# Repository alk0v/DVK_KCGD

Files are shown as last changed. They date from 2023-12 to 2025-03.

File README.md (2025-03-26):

This project is a replica of a color graphic display controller (KCGD) for a DVK computer, reproduced in full accordance with the schematic diagram. Unfortunately, I lost the latest version of the project in KiCAD along with the SSD disk, so the repository contains only what I managed to restore from the backup (about 50% of the finished project). However, the Gerber files were saved.
The boards have been ordered, and one board has been assembled, but unfortunately, there is no way to check its operation. The DVK computer is currently unavailable due to the war in Ukraine.

Цей проект - репліка контролера кольорового графічного дисплею (КЦГД) для комп'ютера ДВК, відтворена у повній відповідності до принципової схеми. На жаль, останню версію проекту в KiCAD я втратив разом з SSD диском, то ж в репозиторії лише те, що вдалося відновити з бекапа (десь 50% готового проекту). Але  зберіглися gerber-файли.
Плати були замовлені, одна плата зібрана, але перевірити її роботу, на жаль, нема можливості. Комп'ютер ДВК зараз недоступний через війну.

gerber_image
kcgd_pcb2
kcgd_pcb1

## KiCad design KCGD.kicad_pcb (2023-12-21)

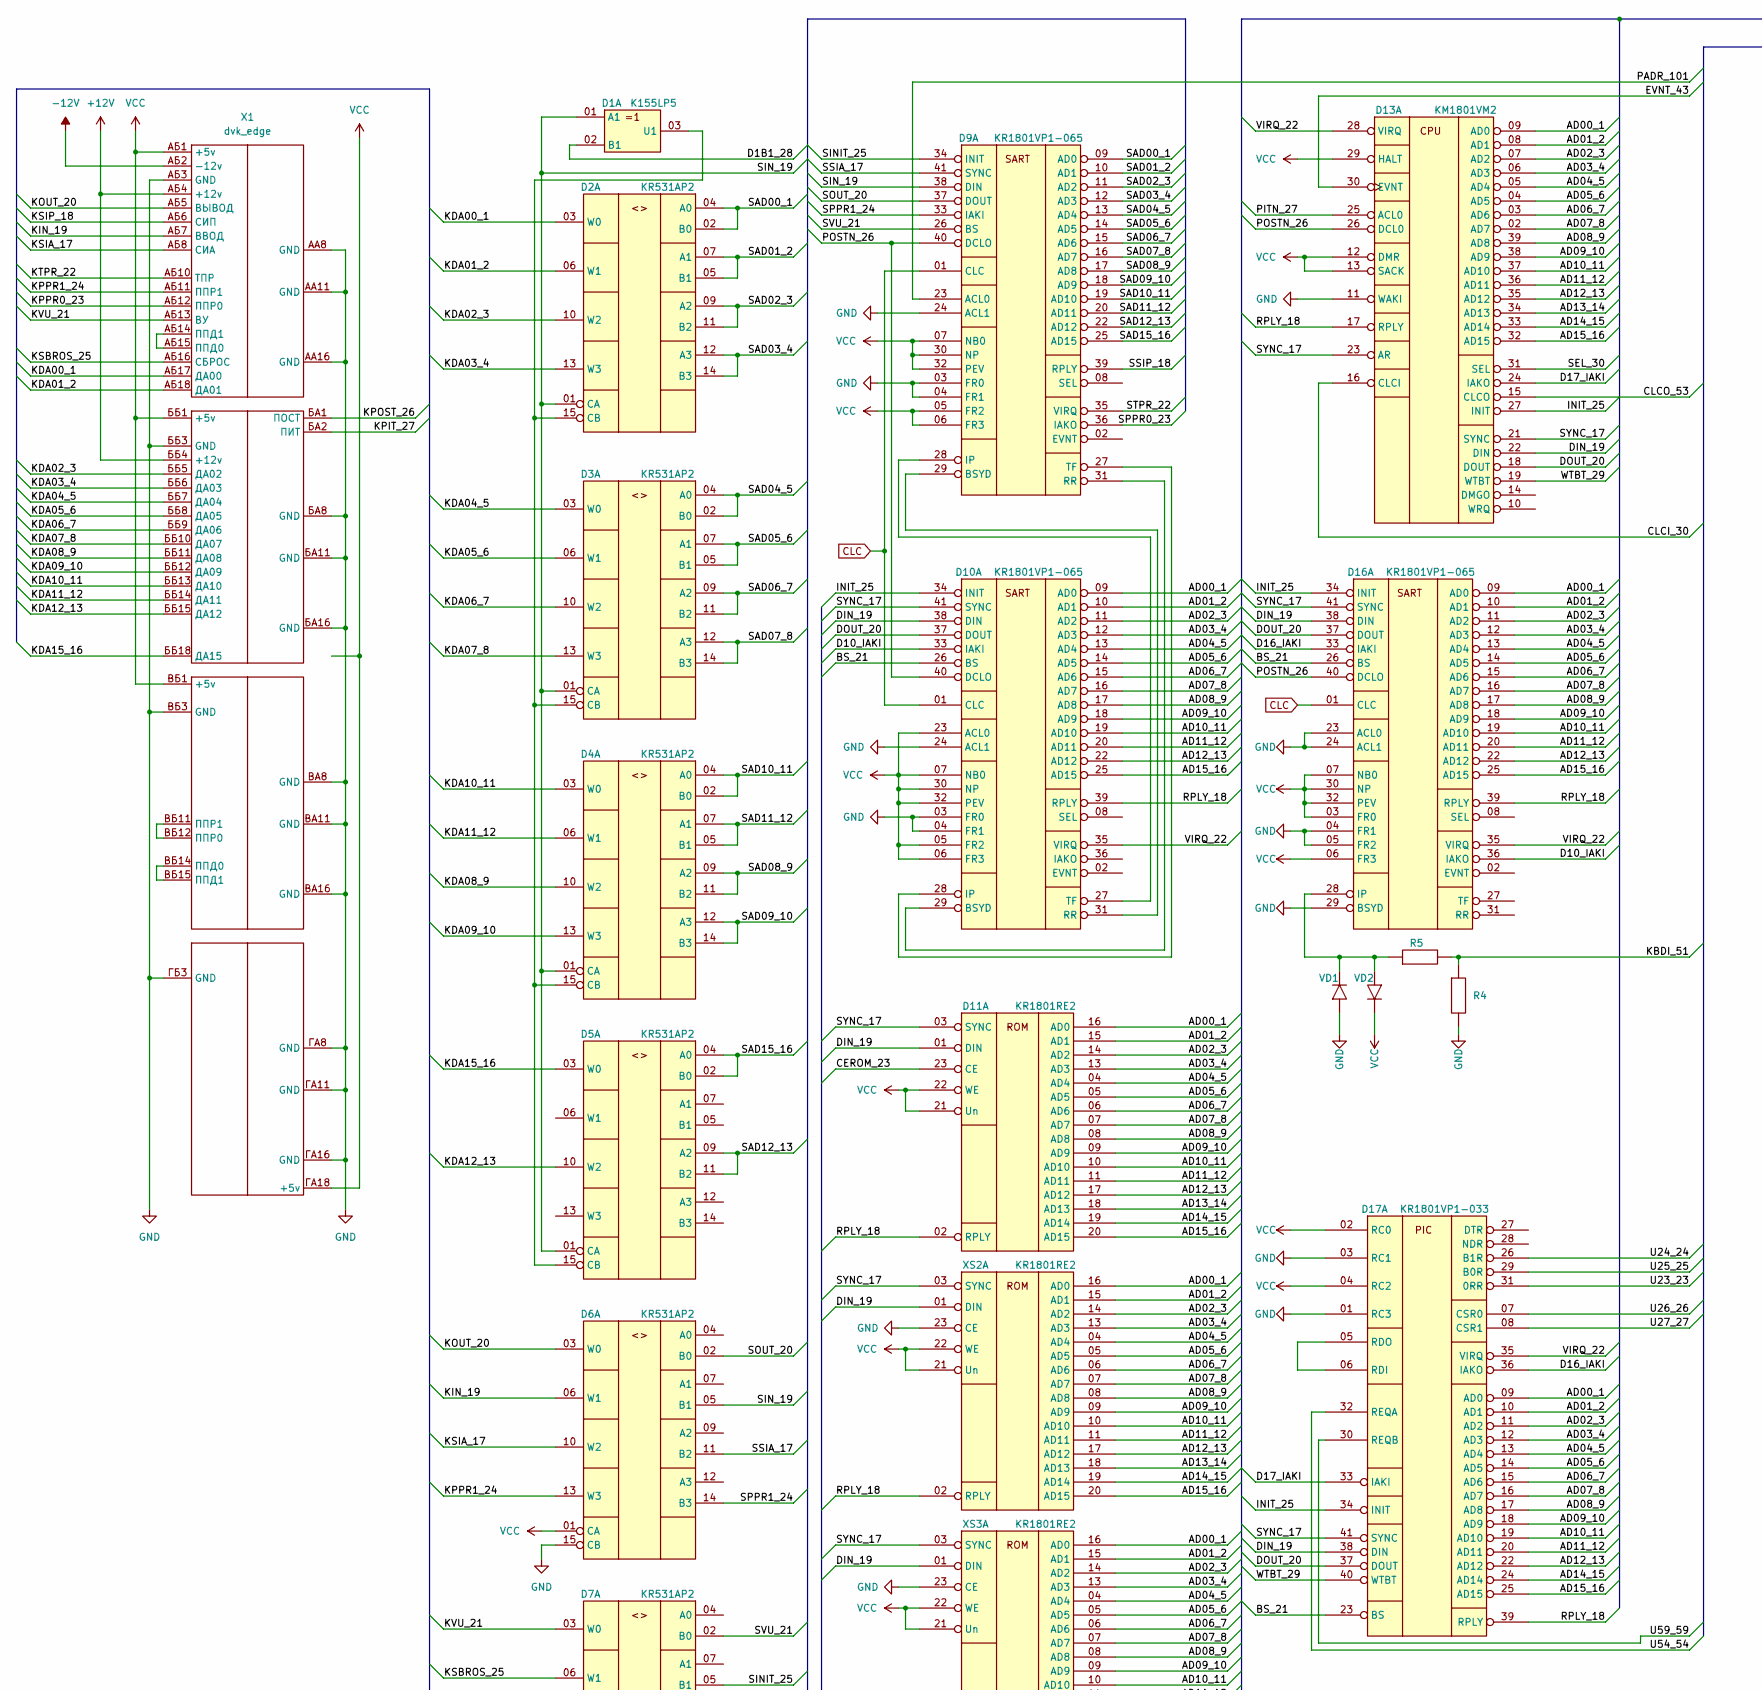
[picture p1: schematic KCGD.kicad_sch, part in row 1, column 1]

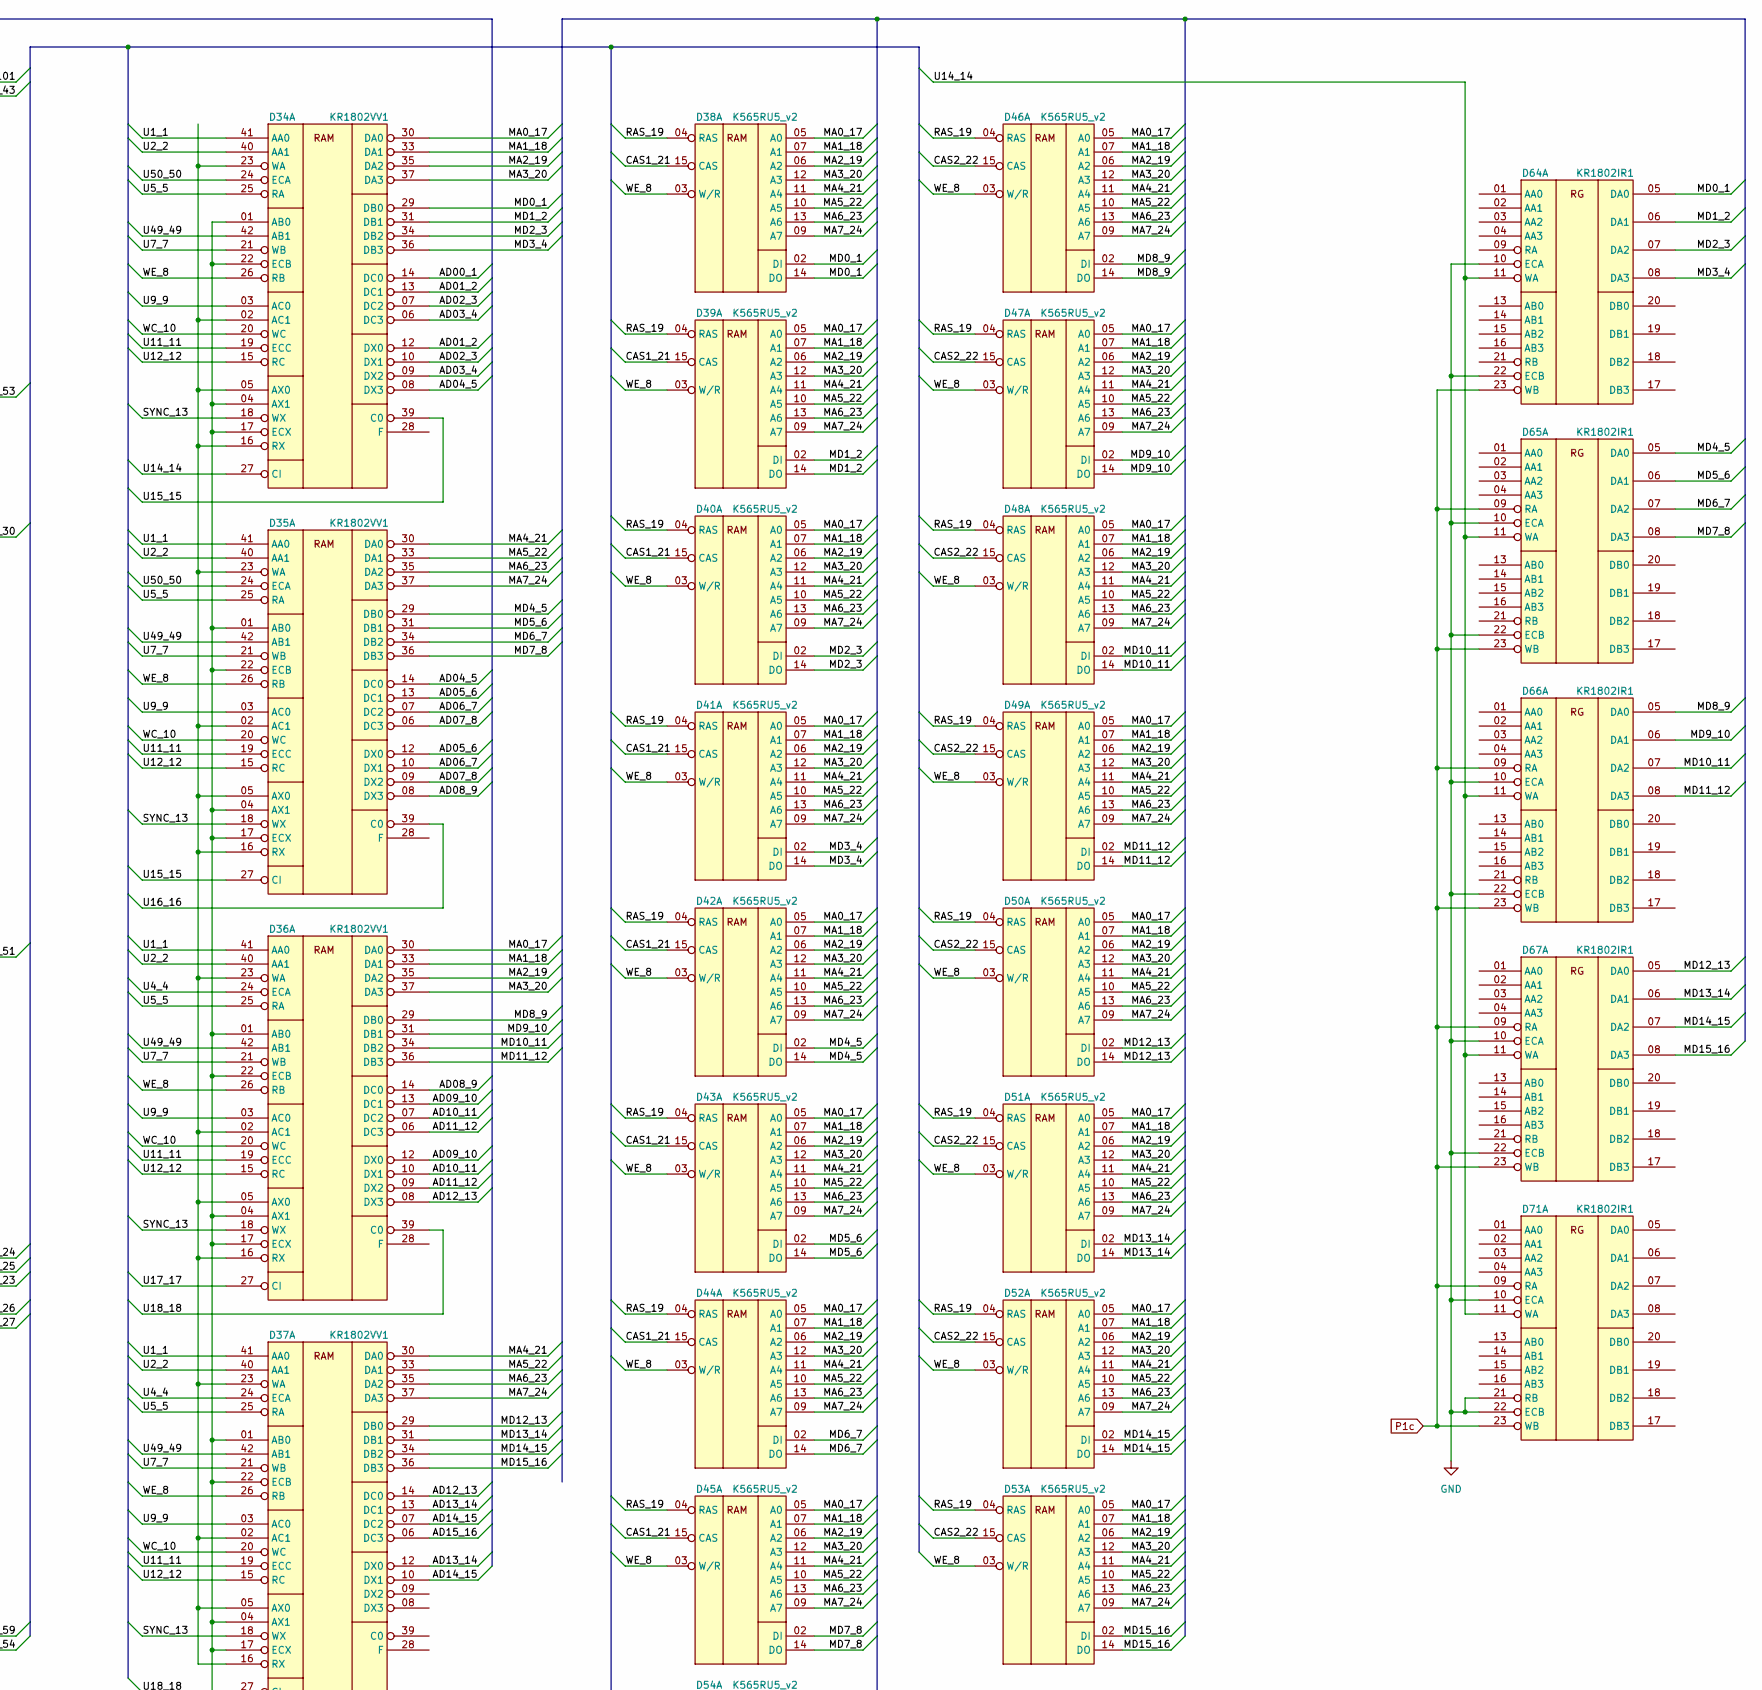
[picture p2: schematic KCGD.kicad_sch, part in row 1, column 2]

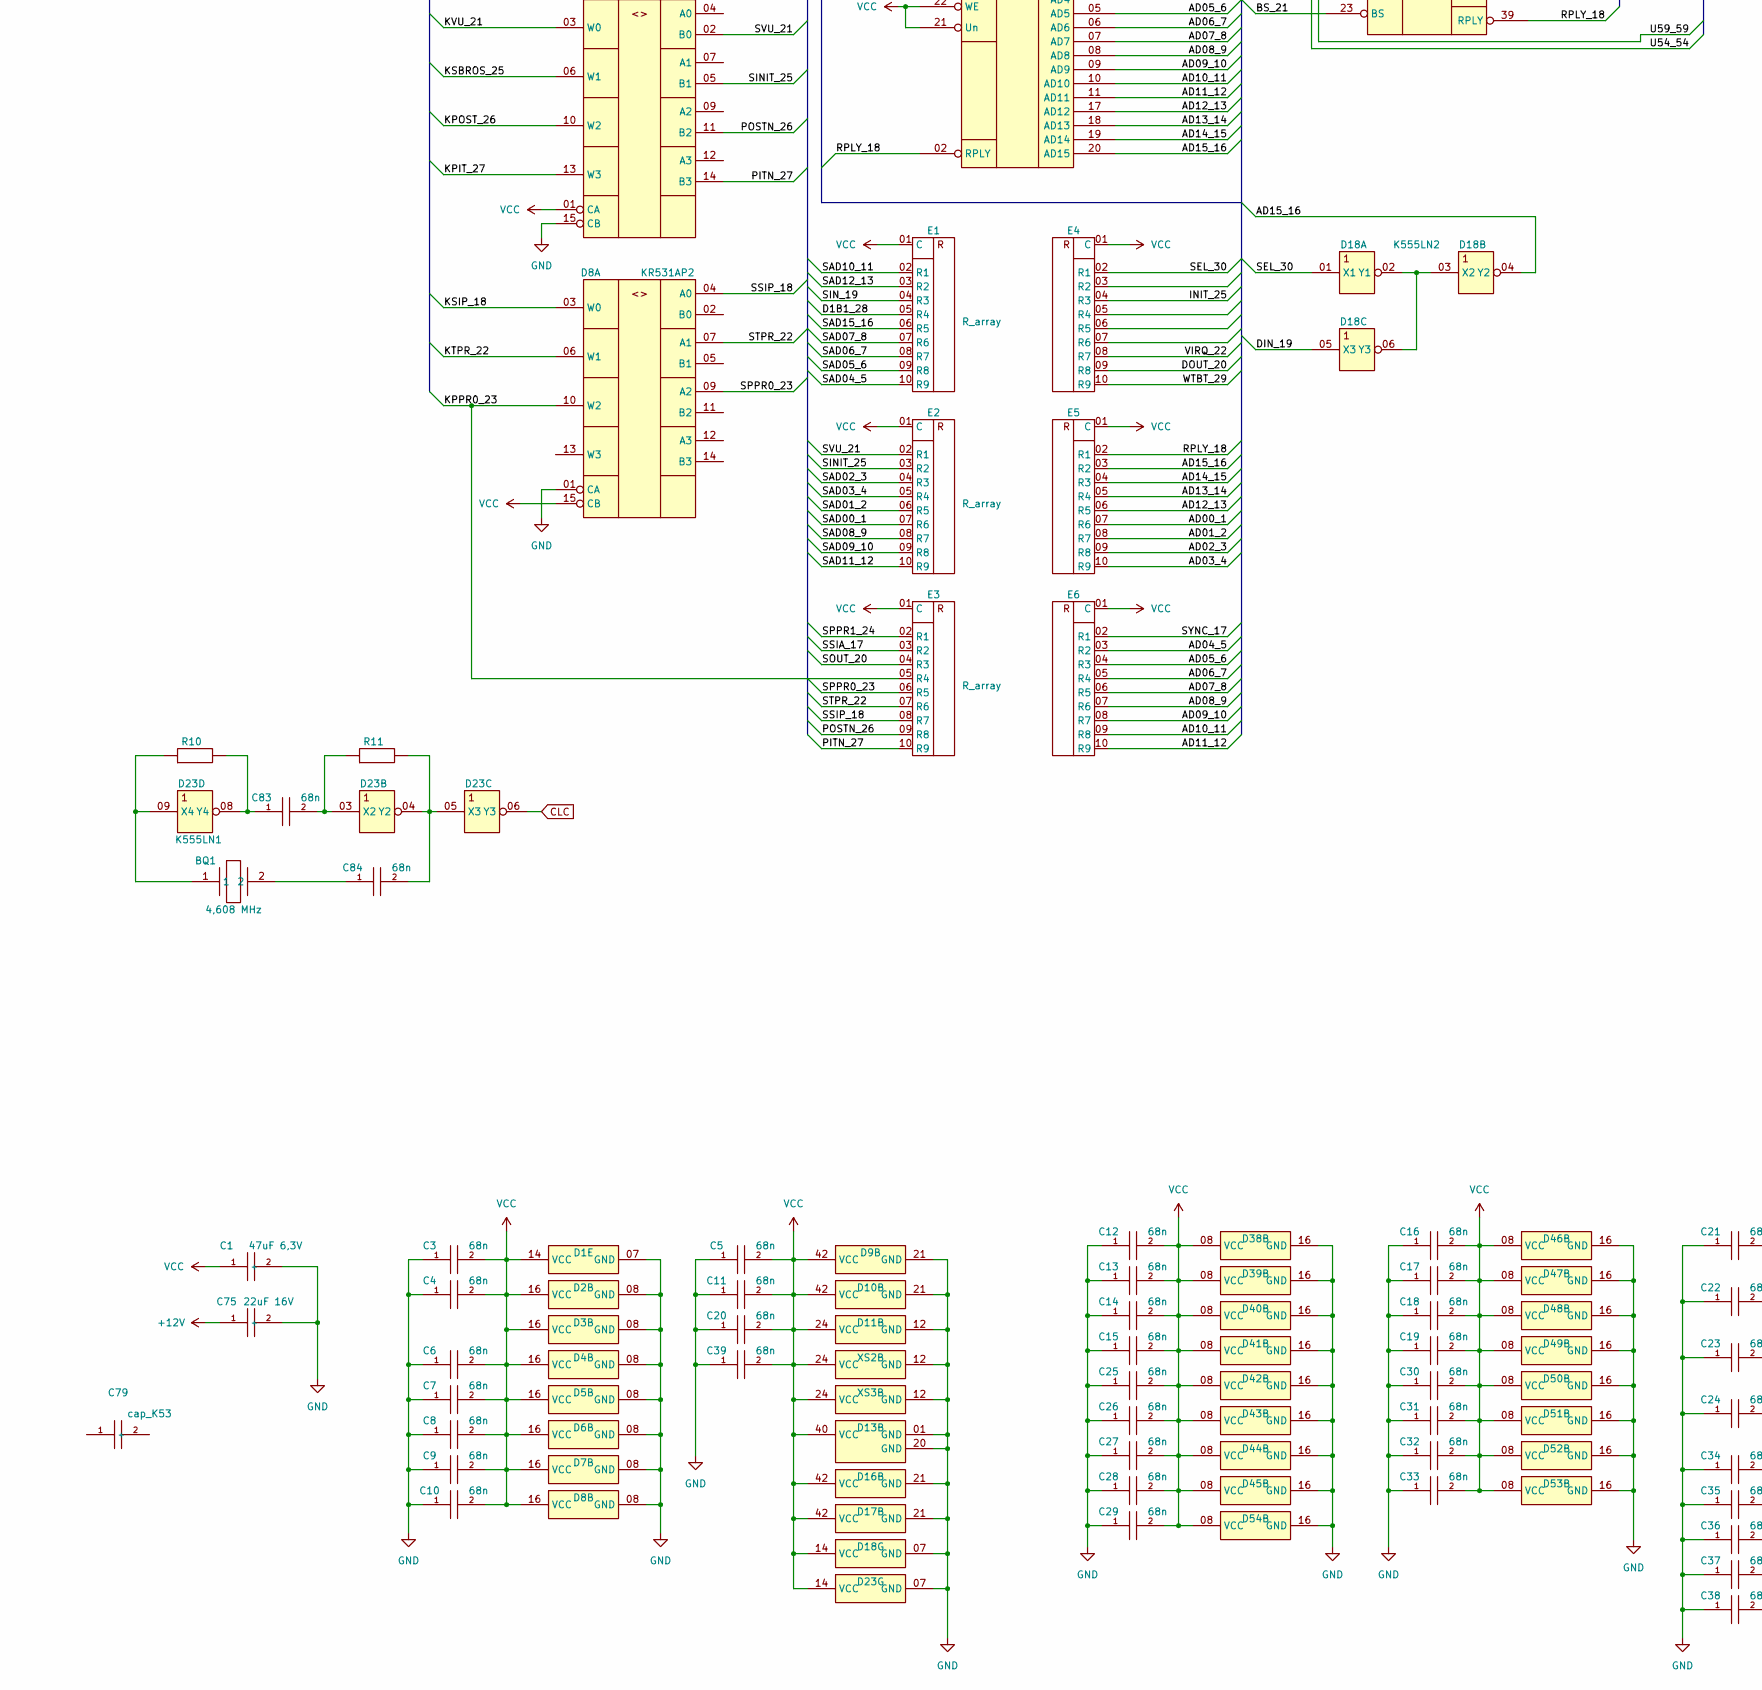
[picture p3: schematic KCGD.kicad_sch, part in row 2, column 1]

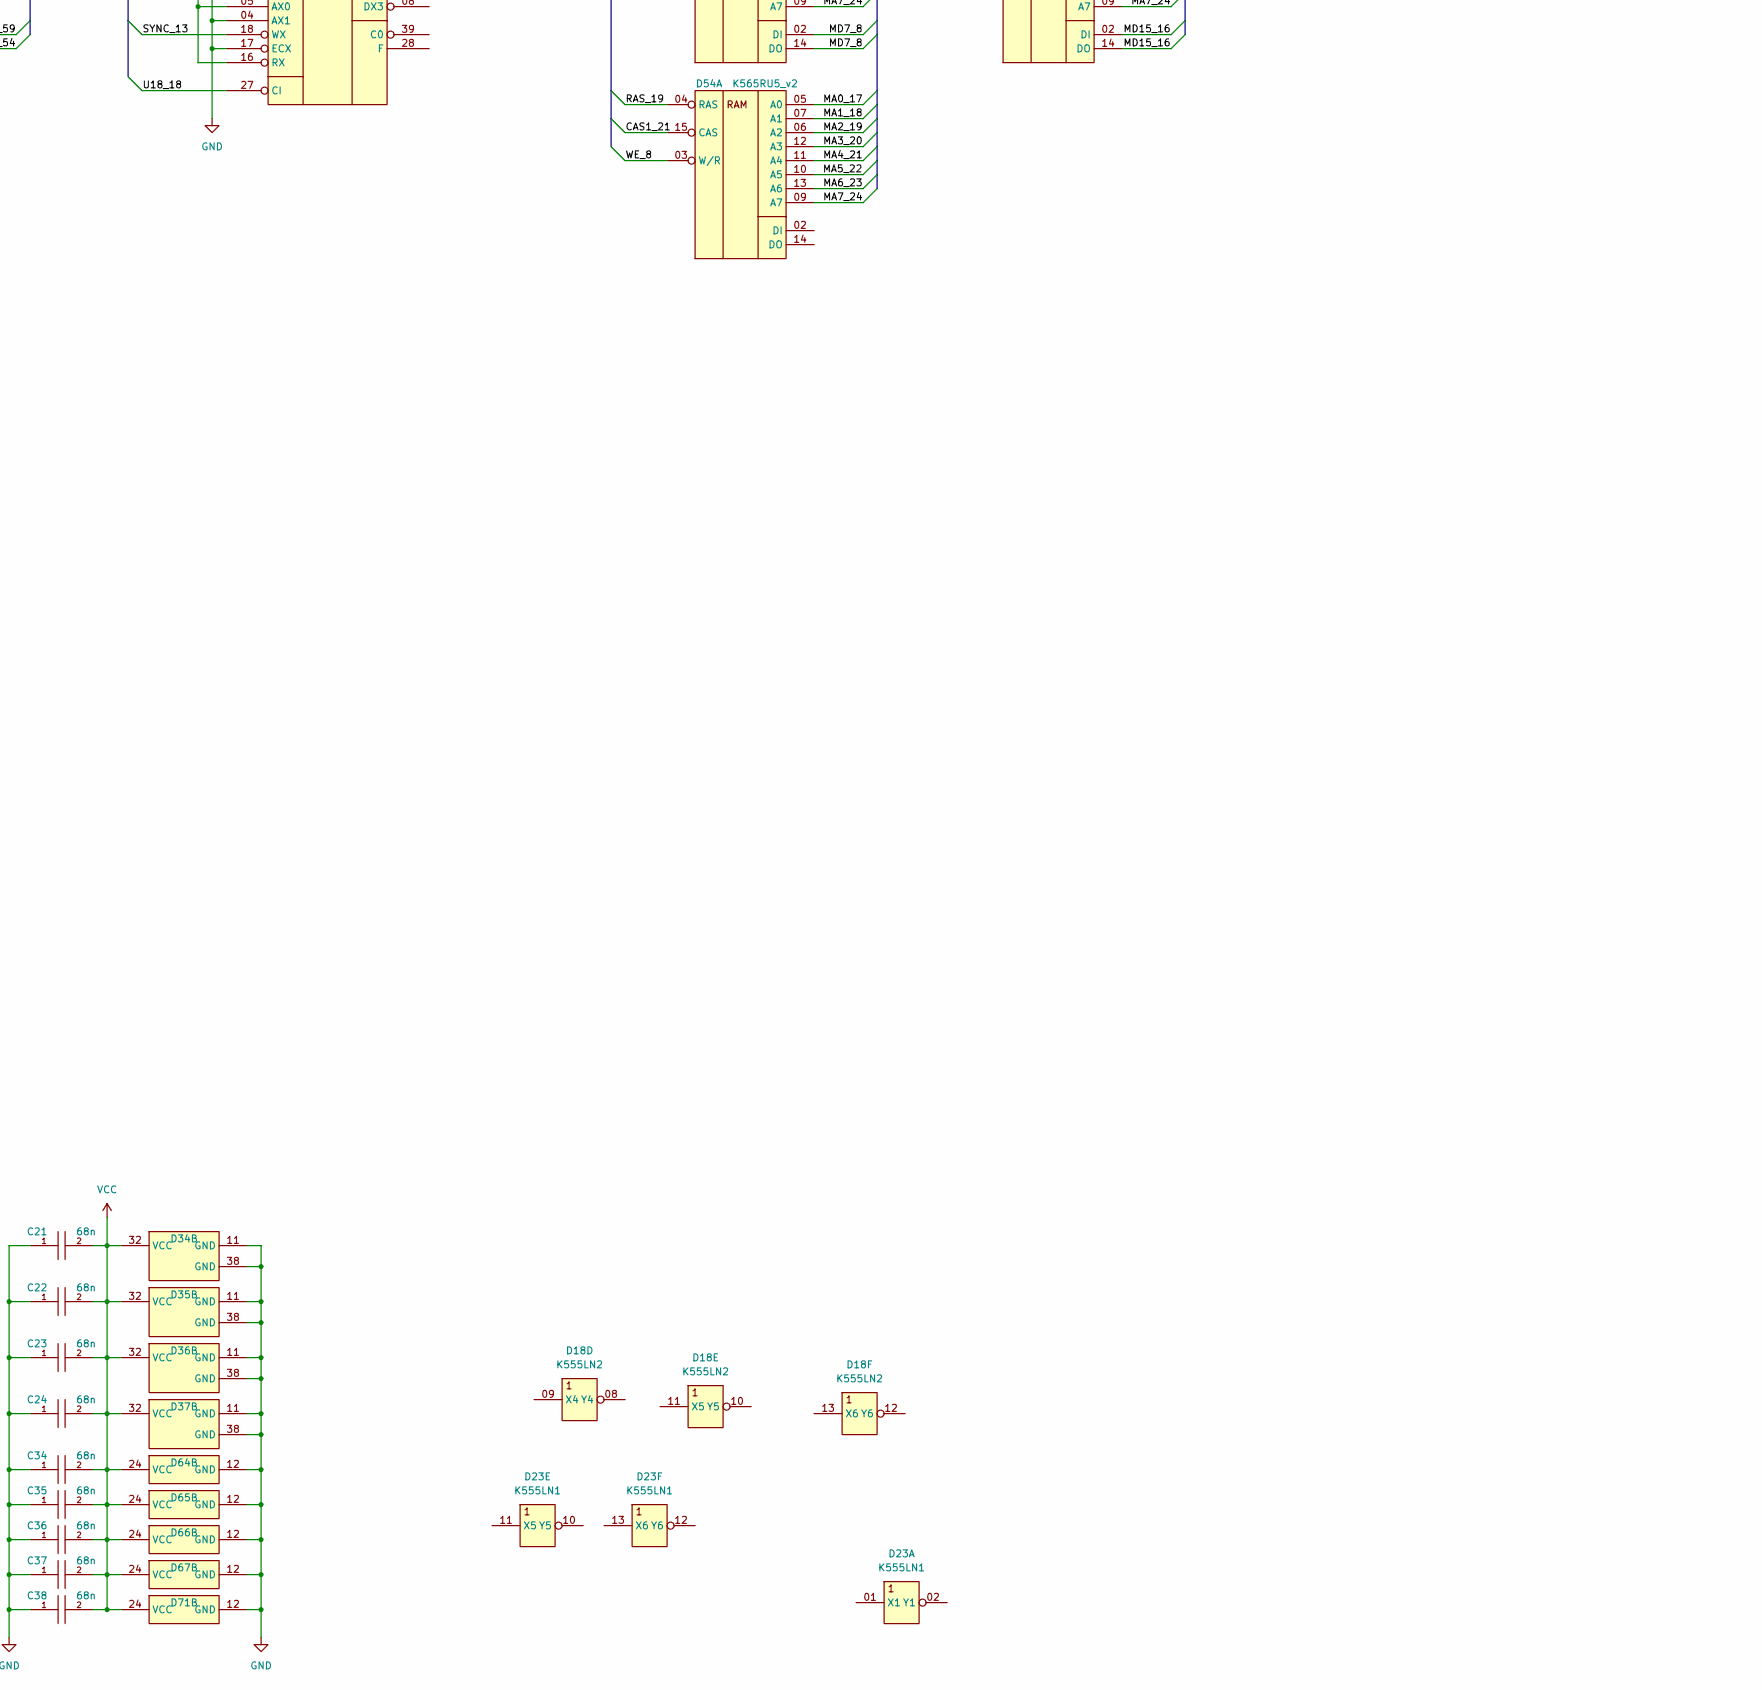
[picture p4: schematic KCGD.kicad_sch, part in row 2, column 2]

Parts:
BQ1: 4,608 MHz; Quartz
C1: 47uF 6,3V; cap_K53
C3, C4, C5, C6, C7, C8, C9, C10, C11, C12, C13, C14, C15, C16, C17, C18, C19, C20, C21, C22, C23, C24, C25, C26, C27, C28, C29, C30, C31, C32, C33, C34, C35, C36, C37, C38, C39, C83, C84: 68n; cap_5mm
C75: 22uF 16V; cap_K53
C79: cap_K53
D1: K155LP5; 201.14-8
D2, D3, D4, D5, D6, D7, D8: KR531AP2; 201.16.5
D9, D10, D16: КR1801VP1-065; 429.42-5
D11: KR1801RE2; 239.24-2
D13: KM1801VM2; 2123.40-6
D17: KR1801VP1-033; 429.42-5
D18: K555LN2; 201.14-8
D23: K555LN1; 201.14-8
D34, D35, D36, D37: KR1802VV1; 429.42-5
D38, D39, D40, D41, D42, D43, D44, D45, D46, D47, D48, D49, D50, D51, D52, D53, D54: K565RU5_v2; 201.16.5
D64, D65, D66, D67, D71: KR1802IR1; 239.24-2
E1, E2, E3, E4, E5, E6: R_array; row-10
R4: 3,3k; 2pin_125
R5: 62k; 2pin_125
R10, R11: 1k; 2pin_125
VD1, VD2: VD_125; 2pin_125
X1: dvk_edge; dvk_edge_kcgd
XS2, XS3: KR1801RE2; 239.24-2

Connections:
+12V: C75.1 (+), X1.АБ4 (+12v), X1.ББ4 (+12v)
-12V: X1.АБ2 (-12v)
/AD00_1: D10.09 (AD0), D11.16 (AD0), D13.09 (AD0), D16.09 (AD0), D17.09 (AD0), D34.14 (DC0), E5.07 (R6), XS2.16 (AD0), XS3.16 (AD0)
/AD01_2: D10.10 (AD1), D11.15 (AD1), D13.08 (AD1), D16.10 (AD1), D17.10 (AD1), D34.12 (DX0), D34.13 (DC1), E5.08 (R7), XS2.15 (AD1), XS3.15 (AD1)
/AD02_3: D10.11 (AD2), D11.14 (AD2), D13.07 (AD2), D16.11 (AD2), D17.11 (AD2), D34.07 (DC2), D34.10 (DX1), E5.09 (R8), XS2.14 (AD2), XS3.14 (AD2)
/AD03_4: D10.12 (AD3), D11.13 (AD3), D13.06 (AD3), D16.12 (AD3), D17.12 (AD3), D34.06 (DC3), D34.09 (DX2), E5.10 (R9), XS2.13 (AD3), XS3.13 (AD3)
/AD04_5: D10.13 (AD4), D11.04 (AD4), D13.05 (AD4), D16.13 (AD4), D17.13 (AD4), D34.08 (DX3), D35.14 (DC0), E6.03 (R2), XS2.04 (AD4), XS3.04 (AD4)
/AD05_6: D10.14 (AD5), D11.05 (AD5), D13.04 (AD5), D16.14 (AD5), D17.14 (AD5), D35.12 (DX0), D35.13 (DC1), E6.04 (R3), XS2.05 (AD5), XS3.05 (AD5)
/AD06_7: D10.15 (AD6), D11.06 (AD6), D13.03 (AD6), D16.15 (AD6), D17.15 (AD6), D35.07 (DC2), D35.10 (DX1), E6.05 (R4), XS2.06 (AD6), XS3.06 (AD6)
/AD07_8: D10.16 (AD7), D11.07 (AD7), D13.02 (AD7), D16.16 (AD7), D17.16 (AD7), D35.06 (DC3), D35.09 (DX2), E6.06 (R5), XS2.07 (AD7), XS3.07 (AD7)
/AD08_9: D10.17 (AD8), D11.08 (AD8), D13.39 (AD8), D16.17 (AD8), D17.17 (AD8), D35.08 (DX3), D36.14 (DC0), E6.07 (R6), XS2.08 (AD8), XS3.08 (AD8)
/AD09_10: D10.18 (AD9), D11.09 (AD9), D13.38 (AD9), D16.18 (AD9), D17.18 (AD9), D36.12 (DX0), D36.13 (DC1), E6.08 (R7), XS2.09 (AD9), XS3.09 (AD9)
/AD10_11: D10.19 (AD10), D11.10 (AD10), D13.37 (AD10), D16.19 (AD10), D17.19 (AD10), D36.07 (DC2), D36.10 (DX1), E6.09 (R8), XS2.10 (AD10), XS3.10 (AD10)
/AD11_12: D10.20 (AD11), D11.11 (AD11), D13.36 (AD11), D16.20 (AD11), D17.20 (AD11), D36.06 (DC3), D36.09 (DX2), E6.10 (R9), XS2.11 (AD11), XS3.11 (AD11)
/AD12_13: D10.22 (AD12), D11.17 (AD12), D13.35 (AD12), D16.22 (AD12), D17.22 (AD12), D36.08 (DX3), D37.14 (DC0), E5.06 (R5), XS2.17 (AD12), XS3.17 (AD12)
/AD13_14: D11.18 (AD13), D13.34 (AD13), D37.12 (DX0), D37.13 (DC1), E5.05 (R4), XS2.18 (AD13), XS3.18 (AD13)
/AD14_15: D11.19 (AD14), D13.33 (AD14), D17.24 (AD14), D37.07 (DC2), D37.10 (DX1), E5.04 (R3), XS2.19 (AD14), XS3.19 (AD14)
/AD15_16: D11.20 (AD15), D13.32 (AD15), D16.25 (AD15), D17.25 (AD15), D18.04 (Y2), D37.06 (DC3), E5.03 (R2), XS2.20 (AD15), XS3.20 (AD15)
/BS_21: D10.26 (BS), D16.26 (BS), D17.23 (BS)
/CAS1_21: D38.15 (CAS), D39.15 (CAS), D40.15 (CAS), D41.15 (CAS), D42.15 (CAS), D43.15 (CAS), D44.15 (CAS), D45.15 (CAS), D54.15 (CAS)
/CAS2_22: D46.15 (CAS), D47.15 (CAS), D48.15 (CAS), D49.15 (CAS), D50.15 (CAS), D51.15 (CAS), D52.15 (CAS), D53.15 (CAS)
/CEROM_23: D11.23 (CE)
/CLCI_30: D13.16 (CLCI)
/CLCO_53: D13.15 (CLCO)
/D1B1_28: D1.02 (B1), E1.05 (R4)
/D10_IAKI: D10.33 (IAKI), D16.36 (IAKO)
/D16_IAKI: D16.33 (IAKI), D17.36 (IAKO)
/D17_IAKI: D13.24 (IAKO), D17.33 (IAKI)
/DIN_19: D10.38 (DIN), D11.01 (DIN), D13.22 (DIN), D16.38 (DIN), D17.38 (DIN), D18.05 (X3), XS2.01 (DIN), XS3.01 (DIN)
/DOUT_20: D10.37 (DOUT), D13.18 (DOUT), D16.37 (DOUT), D17.37 (DOUT), E4.09 (R8)
/EVNT_43: D13.30 (EVNT)
/INIT_25: D10.34 (INIT), D13.27 (INIT), D16.34 (INIT), D17.34 (INIT), E4.04 (R3)
/KBDI_51: R4.1, R5.2
/KDA00_1: D2.03 (W0), X1.АБ17 (ДА00)
/KDA01_2: D2.06 (W1), X1.АБ18 (ДА01)
/KDA02_3: D2.10 (W2), X1.ББ5 (ДА02)
/KDA03_4: D2.13 (W3), X1.ББ6 (ДА03)
/KDA04_5: D3.03 (W0), X1.ББ7 (ДА04)
/KDA05_6: D3.06 (W1), X1.ББ8 (ДА05)
/KDA06_7: D3.10 (W2), X1.ББ9 (ДА06)
/KDA07_8: D3.13 (W3), X1.ББ10 (ДА07)
/KDA08_9: D4.10 (W2), X1.ББ11 (ДА08)
/KDA09_10: D4.13 (W3), X1.ББ12 (ДА09)
/KDA10_11: D4.03 (W0), X1.ББ13 (ДА10)
/KDA11_12: D4.06 (W1), X1.ББ14 (ДА11)
/KDA12_13: D5.10 (W2), X1.ББ15 (ДА12)
/KDA15_16: D5.03 (W0), X1.ББ18 (ДА15)
/KIN_19: D6.06 (W1), X1.АБ7 (ВВОД)
/KOUT_20: D6.03 (W0), X1.АБ5 (ВЫВОД)
/KPIT_27: D7.13 (W3), X1.БА2 (ПИТ)
/KPOST_26: D7.10 (W2), X1.БА1 (ПОСТ)
/KPPR0_23: D8.10 (W2), E3.05 (R4), X1.АБ12 (ППР0)
/KPPR1_24: D6.13 (W3), X1.АБ11 (ППР1)
/KSBROS_25: D7.06 (W1), X1.АБ16 (СБРОС)
/KSIA_17: D6.10 (W2), X1.АБ8 (СИА)
/KSIP_18: D8.03 (W0), X1.АБ6 (СИП)
/KTPR_22: D8.06 (W1), X1.АБ10 (ТПР)
/KVU_21: D7.03 (W0), X1.АБ13 (ВУ)
/MA0_17: D34.30 (DA0), D36.30 (DA0), D38.05 (A0), D39.05 (A0), D40.05 (A0), D41.05 (A0), D42.05 (A0), D43.05 (A0), D44.05 (A0), D45.05 (A0), D46.05 (A0), D47.05 (A0), D48.05 (A0), D49.05 (A0), D50.05 (A0), D51.05 (A0), D52.05 (A0), D53.05 (A0), D54.05 (A0)
/MA1_18: D34.33 (DA1), D36.33 (DA1), D38.07 (A1), D39.07 (A1), D40.07 (A1), D41.07 (A1), D42.07 (A1), D43.07 (A1), D44.07 (A1), D45.07 (A1), D46.07 (A1), D47.07 (A1), D48.07 (A1), D49.07 (A1), D50.07 (A1), D51.07 (A1), D52.07 (A1), D53.07 (A1), D54.07 (A1)
/MA2_19: D34.35 (DA2), D36.35 (DA2), D38.06 (A2), D39.06 (A2), D40.06 (A2), D41.06 (A2), D42.06 (A2), D43.06 (A2), D44.06 (A2), D45.06 (A2), D46.06 (A2), D47.06 (A2), D48.06 (A2), D49.06 (A2), D50.06 (A2), D51.06 (A2), D52.06 (A2), D53.06 (A2), D54.06 (A2)
/MA3_20: D34.37 (DA3), D36.37 (DA3), D38.12 (A3), D39.12 (A3), D40.12 (A3), D41.12 (A3), D42.12 (A3), D43.12 (A3), D44.12 (A3), D45.12 (A3), D46.12 (A3), D47.12 (A3), D48.12 (A3), D49.12 (A3), D50.12 (A3), D51.12 (A3), D52.12 (A3), D53.12 (A3), D54.12 (A3)
/MA4_21: D35.30 (DA0), D37.30 (DA0), D38.11 (A4), D39.11 (A4), D40.11 (A4), D41.11 (A4), D42.11 (A4), D43.11 (A4), D44.11 (A4), D45.11 (A4), D46.11 (A4), D47.11 (A4), D48.11 (A4), D49.11 (A4), D50.11 (A4), D51.11 (A4), D52.11 (A4), D53.11 (A4), D54.11 (A4)
/MA5_22: D35.33 (DA1), D37.33 (DA1), D38.10 (A5), D39.10 (A5), D40.10 (A5), D41.10 (A5), D42.10 (A5), D43.10 (A5), D44.10 (A5), D45.10 (A5), D46.10 (A5), D47.10 (A5), D48.10 (A5), D49.10 (A5), D50.10 (A5), D51.10 (A5), D52.10 (A5), D53.10 (A5), D54.10 (A5)
/MA6_23: D35.35 (DA2), D37.35 (DA2), D38.13 (A6), D39.13 (A6), D40.13 (A6), D41.13 (A6), D42.13 (A6), D43.13 (A6), D44.13 (A6), D45.13 (A6), D46.13 (A6), D47.13 (A6), D48.13 (A6), D49.13 (A6), D50.13 (A6), D51.13 (A6), D52.13 (A6), D53.13 (A6), D54.13 (A6)
/MA7_24: D35.37 (DA3), D37.37 (DA3), D38.09 (A7), D39.09 (A7), D40.09 (A7), D41.09 (A7), D42.09 (A7), D43.09 (A7), D44.09 (A7), D45.09 (A7), D46.09 (A7), D47.09 (A7), D48.09 (A7), D49.09 (A7), D50.09 (A7), D51.09 (A7), D52.09 (A7), D53.09 (A7), D54.09 (A7)
/MD0_1: D34.29 (DB0), D38.02 (DI), D38.14 (DO), D64.05 (DA0)
/MD1_2: D34.31 (DB1), D39.02 (DI), D39.14 (DO), D64.06 (DA1)
/MD2_3: D34.34 (DB2), D40.02 (DI), D40.14 (DO), D64.07 (DA2)
/MD3_4: D34.36 (DB3), D41.02 (DI), D41.14 (DO), D64.08 (DA3)
/MD4_5: D35.29 (DB0), D42.02 (DI), D42.14 (DO), D65.05 (DA0)
/MD5_6: D35.31 (DB1), D43.02 (DI), D43.14 (DO), D65.06 (DA1)
/MD6_7: D35.34 (DB2), D44.02 (DI), D44.14 (DO), D65.07 (DA2)
/MD7_8: D35.36 (DB3), D45.02 (DI), D45.14 (DO), D65.08 (DA3)
/MD8_9: D36.29 (DB0), D46.02 (DI), D46.14 (DO), D66.05 (DA0)
/MD9_10: D36.31 (DB1), D47.02 (DI), D47.14 (DO), D66.06 (DA1)
/MD10_11: D36.34 (DB2), D48.02 (DI), D48.14 (DO), D66.07 (DA2)
/MD11_12: D36.36 (DB3), D49.02 (DI), D49.14 (DO), D66.08 (DA3)
/MD12_13: D37.29 (DB0), D50.02 (DI), D50.14 (DO), D67.05 (DA0)
/MD13_14: D37.31 (DB1), D51.02 (DI), D51.14 (DO), D67.06 (DA1)
/MD14_15: D37.34 (DB2), D52.02 (DI), D52.14 (DO), D67.07 (DA2)
/MD15_16: D37.36 (DB3), D53.02 (DI), D53.14 (DO), D67.08 (DA3)
/PADR_101: D9.23 (ACL0)
/PITN_27: D7.14 (B3), D13.25 (ACL0), E3.10 (R9)
/POSTN_26: D7.11 (B2), D9.40 (DCLO), D10.40 (DCLO), D13.26 (DCL0), D16.40 (DCLO), E3.09 (R8)
/RAS_19: D38.04 (RAS), D39.04 (RAS), D40.04 (RAS), D41.04 (RAS), D42.04 (RAS), D43.04 (RAS), D44.04 (RAS), D45.04 (RAS), D46.04 (RAS), D47.04 (RAS), D48.04 (RAS), D49.04 (RAS), D50.04 (RAS), D51.04 (RAS), D52.04 (RAS), D53.04 (RAS), D54.04 (RAS)
/RPLY_18: D10.39 (RPLY), D11.02 (RPLY), D13.17 (RPLY), D16.39 (RPLY), D17.39 (RPLY), E5.02 (R1), XS2.02 (RPLY), XS3.02 (RPLY)
/SAD00_1: D2.02 (B0), D2.04 (A0), D9.09 (AD0), E2.07 (R6)
/SAD01_2: D2.05 (B1), D2.07 (A1), D9.10 (AD1), E2.06 (R5)
/SAD02_3: D2.09 (A2), D2.11 (B2), D9.11 (AD2), E2.04 (R3)
/SAD03_4: D2.12 (A3), D2.14 (B3), D9.12 (AD3), E2.05 (R4)
/SAD04_5: D3.02 (B0), D3.04 (A0), D9.13 (AD4), E1.10 (R9)
/SAD05_6: D3.05 (B1), D3.07 (A1), D9.14 (AD5), E1.09 (R8)
/SAD06_7: D3.09 (A2), D3.11 (B2), D9.15 (AD6), E1.08 (R7)
/SAD07_8: D3.12 (A3), D3.14 (B3), D9.16 (AD7), E1.07 (R6)
/SAD08_9: D4.09 (A2), D4.11 (B2), D9.17 (AD8), E2.08 (R7)
/SAD09_10: D4.12 (A3), D4.14 (B3), D9.18 (AD9), E2.09 (R8)
/SAD10_11: D4.02 (B0), D4.04 (A0), D9.19 (AD10), E1.02 (R1)
/SAD11_12: D4.05 (B1), D4.07 (A1), D9.20 (AD11), E2.10 (R9)
/SAD12_13: D5.09 (A2), D5.11 (B2), D9.22 (AD12), E1.03 (R2)
/SAD15_16: D5.02 (B0), D5.04 (A0), D9.25 (AD15), E1.06 (R5)
/SEL_30: D13.31 (SEL), D18.01 (X1), E4.02 (R1)
/SINIT_25: D7.05 (B1), D9.34 (INIT), E2.03 (R2)
/SIN_19: D1.01 (A1), D2.01 (CA), D3.01 (CA), D4.01 (CA), D5.01 (CA), D6.05 (B1), D9.38 (DIN), E1.04 (R3)
/SOUT_20: D6.02 (B0), D9.37 (DOUT), E3.04 (R3)
/SPPR0_23: D8.09 (A2), D9.36 (IAKO), E3.06 (R5)
/SPPR1_24: D6.14 (B3), D9.33 (IAKI), E3.02 (R1)
/SSIA_17: D6.11 (B2), D9.41 (SYNC), E3.03 (R2)
/SSIP_18: D8.04 (A0), D9.39 (RPLY), E3.08 (R7)
/STPR_22: D8.07 (A1), D9.35 (VIRQ), E3.07 (R6)
/SVU_21: D7.02 (B0), D9.26 (BS), E2.02 (R1)
/SYNC_13: D34.18 (WX), D35.18 (WX), D36.18 (WX), D37.18 (WX)
/SYNC_17: D10.41 (SYNC), D11.03 (SYNC), D13.21 (SYNC), D13.23 (AR), D16.41 (SYNC), D17.41 (SYNC), E6.02 (R1), XS2.03 (SYNC), XS3.03 (SYNC)
/U1_1: D34.41 (AA0), D35.41 (AA0), D36.41 (AA0), D37.41 (AA0)
/U2_2: D34.40 (AA1), D35.40 (AA1), D36.40 (AA1), D37.40 (AA1)
/U4_4: D36.24 (ECA), D37.24 (ECA)
/U5_5: D34.25 (RA), D35.25 (RA), D36.25 (RA), D37.25 (RA)
/U7_7: D34.21 (WB), D35.21 (WB), D36.21 (WB), D37.21 (WB)
/U9_9: D34.03 (AC0), D35.03 (AC0), D36.03 (AC0), D37.03 (AC0)
/U11_11: D34.19 (ECC), D35.19 (ECC), D36.19 (ECC), D37.19 (ECC)
/U12_12: D34.15 (RC), D35.15 (RC), D36.15 (RC), D37.15 (RC)
/U14_14: D34.27 (CI), D64.11 (WA), D65.11 (WA), D66.11 (WA), D67.11 (WA), D71.11 (WA)
/U15_15: D34.39 (C0), D35.27 (CI)
/U16_16: D35.39 (C0)
/U17_17: D36.27 (CI)
/U18_18: D36.39 (C0), D37.27 (CI)
/U23_23: D17.31 (0RR)
/U24_24: D17.26 (B1R)
/U25_25: D17.29 (B0R)
/U26_26: D17.07 (CSR0)
/U27_27: D17.08 (CSR1)
/U49_49: D34.42 (AB1), D35.42 (AB1), D36.42 (AB1), D37.42 (AB1)
/U50_50: D34.24 (ECA), D35.24 (ECA)
/U54_54: D17.32 (REQA)
/U59_59: D17.30 (REQB)
/VIRQ_22: D10.35 (VIRQ), D13.28 (VIRQ), D16.35 (VIRQ), D17.35 (VIRQ), E4.08 (R7)
/WC_10: D34.20 (WC), D35.20 (WC), D36.20 (WC), D37.20 (WC)
/WE_8: D34.26 (RB), D35.26 (RB), D36.26 (RB), D37.26 (RB), D38.03 (W/R), D39.03 (W/R), D40.03 (W/R), D41.03 (W/R), D42.03 (W/R), D43.03 (W/R), D44.03 (W/R), D45.03 (W/R), D46.03 (W/R), D47.03 (W/R), D48.03 (W/R), D49.03 (W/R), D50.03 (W/R), D51.03 (W/R), D52.03 (W/R), D53.03 (W/R), D54.03 (W/R)
/WTBT_29: D13.19 (WTBT), D17.40 (WTBT), E4.10 (R9)
CLC: D9.01 (CLC), D10.01 (CLC), D16.01 (CLC), D23.06 (Y3)
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

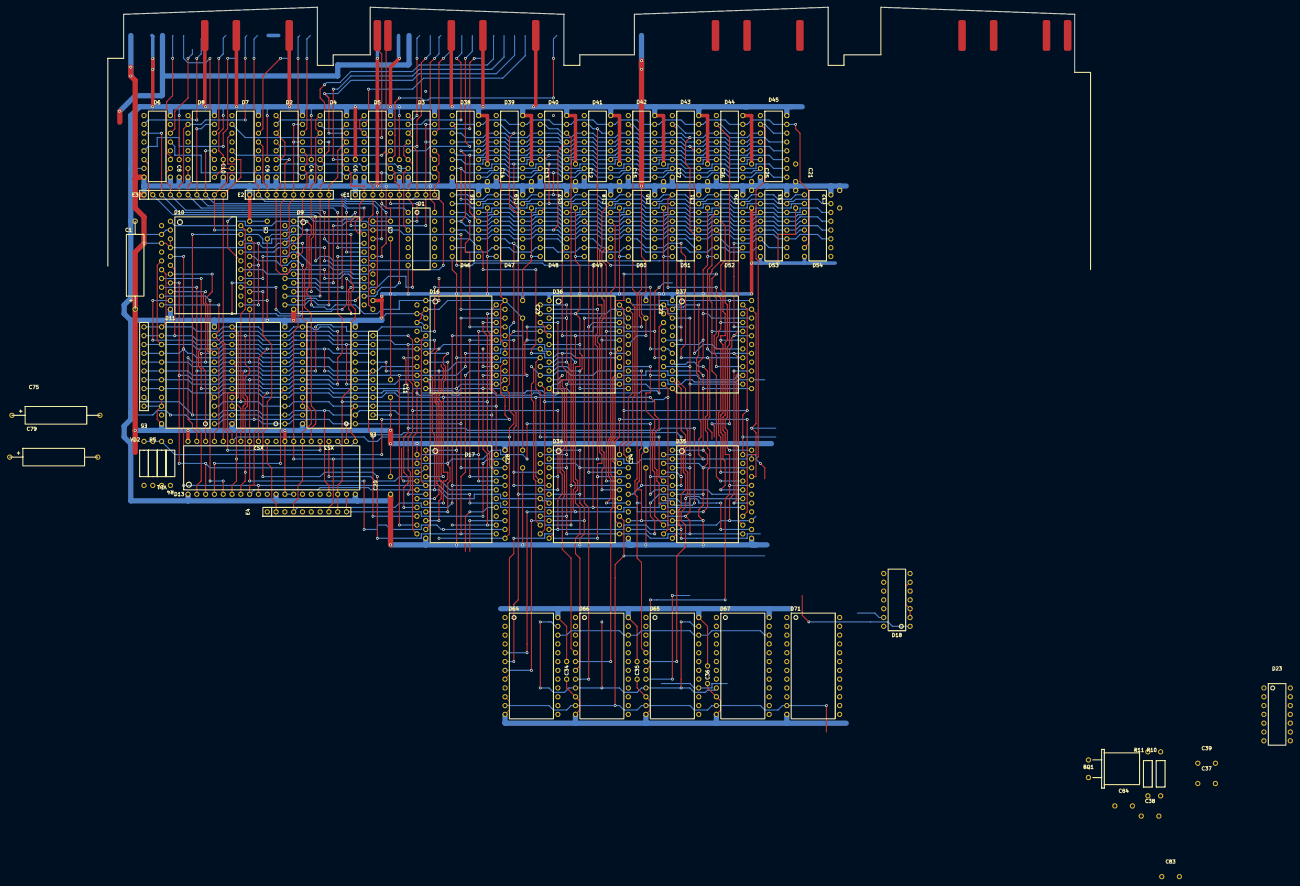
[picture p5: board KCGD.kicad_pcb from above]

Board: 2 copper layers, 100 parts (0 on the bottom side), 145 nets.
